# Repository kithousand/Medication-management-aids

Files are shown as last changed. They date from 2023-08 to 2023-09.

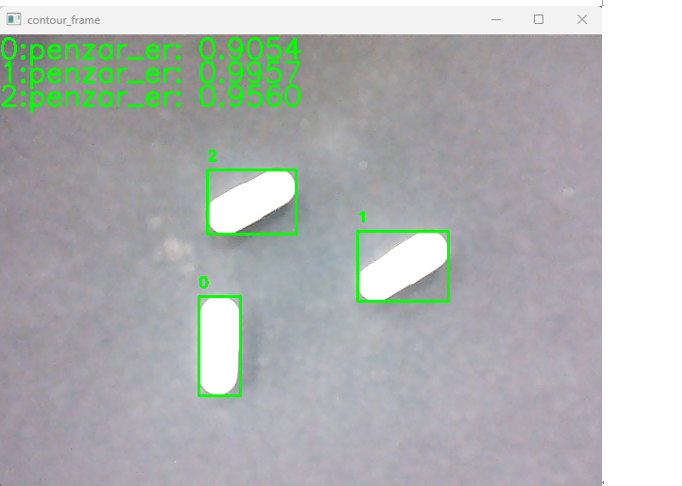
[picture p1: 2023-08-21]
AI/result.png

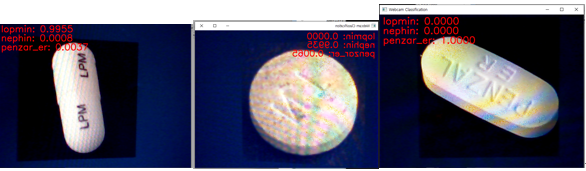
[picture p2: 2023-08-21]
AI/result1.png

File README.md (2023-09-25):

# 팀_알약보조관리


# 문제점정의

## 최근 통계로 알아보는 노인층의 복약관리 동향


## 사용자 분석 – 우리 주변의 노인들


## 사용자 분석 – 전문가 인터뷰


# 유즈케이스 시나리오

고령화 저출산은 한국에서 심각한 사회현상중 하나이다

독거노인들은 복약관리등 케어를 받을 금전적 여유나

인간관계가 부족하기때문에 복약관리를 받기가 쉽지않다

또한 노화에 인한 기억력 감퇴때문에 약을 먹을 시기를 놓치기도 한다

이번프로젝트는 독거노인들이 혼자서 약을 먹는것을 잊지않고 먹게 해주고

실수로 중복약제를 먹는 것을 예방해준다

## High level design


## Work breakdown sheet

									
## 동작구조도


## Flow Chart


## 역할 분담
팀장 하종찬(기획/프로젝트 매니저)

팀원 문상원(개발자, AI 개발)

팀원 한재욱(개발자, 임베디드 개발)

팀원 엄기천(개발자, 알고리즘 개발)

## 그 외 기타 사항 - SW dependency, 동작 환경, 제한 사항 등을 기술

## 핵심 기술


## 시연 영상, 제작영상 URL
• 제작영상 : https://www.youtube.com/watch?v=2JGMzi57F4s&t=31s

• 시연영상 : https://www.youtube.com/shorts/7cosngZtbhQ

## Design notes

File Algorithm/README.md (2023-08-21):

# pill_eat_source - ki_thousand

## 동작환경
OS : Debian GNU/Linux 11 이상
Python : 3.9.2 이상

## 필요한 패키지 설치 : requirements.txt
```
$ pip install -r requirements.txt
```

## 실행파일이름 : main.py

```
$ python3 main.py
```

## class별 pill_eat 기능설명

### Message.py
#### LCD와 SPEAKER로 사용자에게 알림기능파일

```
class Message:
  - welcome_Pilleat(): 웰컴필잇!!!
  - fill_Pill(): 트레이에 알약을 채워달라고 알려주는 기능
  - eatTime_Pill(): 약을 복용해야하는 시간을 알려주는 기능
  - info_Pill(): 약의 이름과 성분 설명해주는 기능
  - overlap_Pill(): 중복된 약을 알려주는 기능
  - loading_Wait(): 로딩중임을 표시하는 기능
  - display_Time_now(): 현재시간을 표시해주는 기능
```

### led.py
#### LED와 SENSOR를 제어하는 파일

```
class led:
  - led_on(): LED를 켜는기능 (주로 알약분석시 활용)
  - led_off(): LED를 끄는기능 

class sensor:
  - sensor_state(): IR SENSOR 감지값을 읽는기능 (TRAY가 있는지 확인할때 사용)
```

### detect_Pill.py
#### AI모델을 사용하는 파일

```
class analysis_pill:
  - analysis_Pill(): TRAY에 있는 알약을 분석하는기능 (LCD와 SPEAKER출력도 포함되어있음)
```

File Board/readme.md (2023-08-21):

# 보드세팅

## 하드웨어 세팅

### 배터리팩 제작
그림1
BMS 보호회로에 각 맞는 리튬이온배터리 단자를 연결해줍니다.
알맞은 입출력단자에 QC3.0 출력단자와 C타입 입력단자를 연결합니다.

### LCD, 카메라, IR 근접센서, LED 모듈 고정
그림4
기존 가공된 외관에 LCD와 카메라, IR 근접센서, LED를 글루건이나 본드로 고정해줍니다.

### 핀 연결
그림5
핀 맵을 참고하여 라즈베리파이에 핀을 연결해줍니다.

### 스피커와 배터리 모듈 연결
그림6
스피커는 라즈베리파이 USB단자에 연결합니다.
배터리팩은 라즈베리파이 C타입전원 단자에 연결합니다.

### 완성본
그림7

## 라즈베리파이 내부 세팅

### Raspberry Pi OS 라즈비안 설치
https://www.raspberrypi.com/software/
접속하여서 OS 소프트웨어를 다운받습니다.
OS로 라즈비안 64-Bit를 선택합니다.

noname01
고급옵션(밑의 톱니바퀴)을 선택하여 SSH 사용과 무선 LAN을 설정해줍니다.
SSH 사용 => 비밀번호 인증 사용 => 사용자 이름 및 비밀번호 설정 => 무선 LAN 설정 => locale 설정 지정

### 라즈베리파이 초기 설정
윈도우 cmd창에서 nmap으로 라즈베리파이의 IP주소를 찾습니다.
```
$ nmap -sn 192.168.0.0/24
```
putty를 실행하여 라즈베리파이에 접속하여 업데이트를 진행해줍니다.
```
$ sudo apt update
```
```
$ sudo apt upgrade
```
/etc/dhcpcd.conf 파일 열어서 라즈베리파이에 고정 IP를 설정합니다
```
$ sudo apt install vim
```
```
$ sudo vim /etc/dhcpcd.conf
```
파일 맨 아래에 아래의 내용을 추가해줍니다.
```
interface wlan0
static ip_address = 
static routers =
```
networking service 재시작해준 이후 reboot해줍니다.
```
$ sudo /etc/init.d/networking restart
```
```
$ sudo reboot
```

### 라즈베리파이 원격 GUI 접속
xrdp를 설치해줍니다.
```
$ sudo apt install xrdp
```
이후 원격접속을 설정해줍니다.
```
$ sudo raspi-config
```
Interface Options => VNC => enable 하기
접속이 안될경우
아래 코드로 원격접속화면을 생성해줍니다.
```
$ vncserver-virtual
$ vncserver-virtual –geometry 1280x1024
```
https://www.realvnc.com/en/connect/download/viewer/
접속하여서 VNC Viewer를 설치합니다.

### 카메라 설정하기
```
$ sudo raspi-config
```
Interface Options => Legacy Camera => enable 하기 => reboot

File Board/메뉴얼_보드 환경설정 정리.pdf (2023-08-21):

1. Raspberry Pi OS 라즈비안 설치
1) OS 소프트웨어 다운
https://www.raspberrypi.com/software/

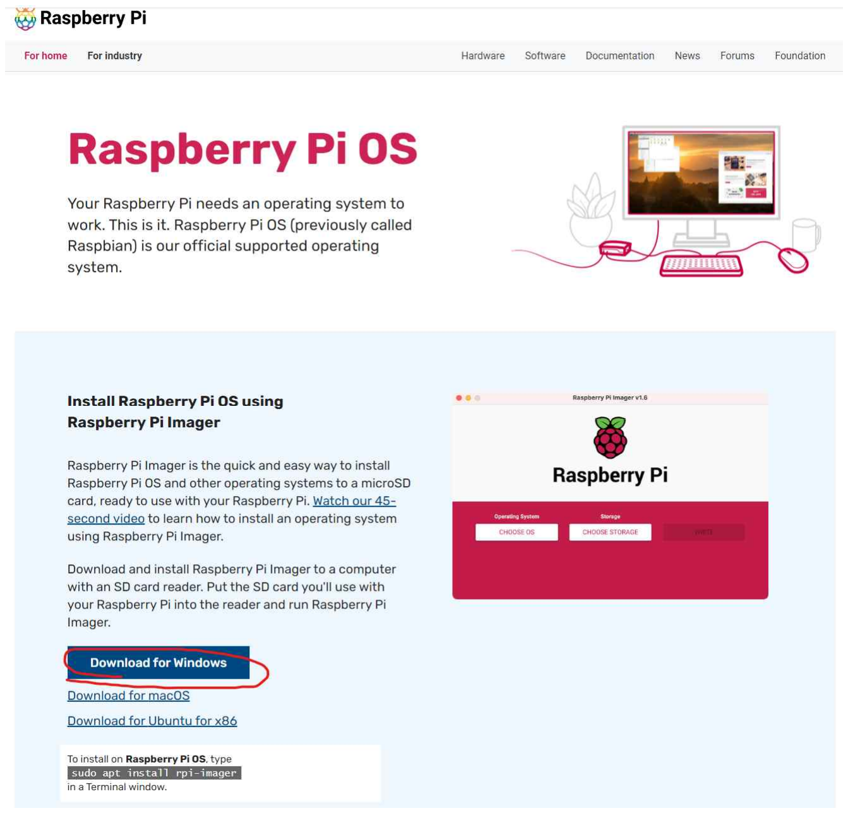
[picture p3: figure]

2) OS 선택

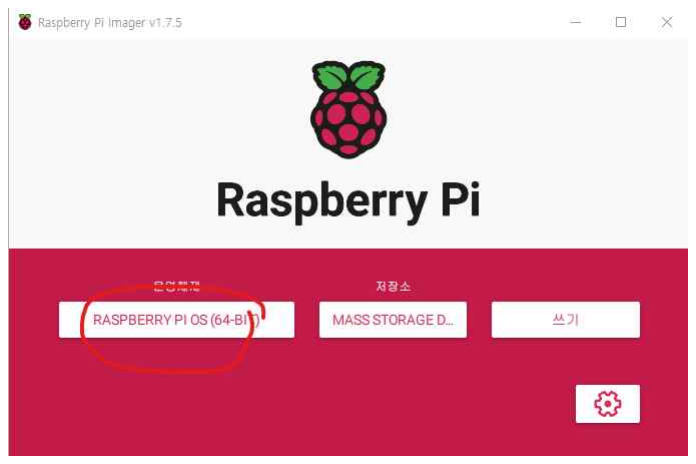
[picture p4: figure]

3) 고급 옵션 설정
SSH 사용 => 비밀번호 인증 사용 => 사용 자 이름 및 비밀번호 설정 => 무선 LAN 설 정 => locale 설정 지정
2. 라즈베리파이 초기 설정
1) 윈도우 cmd창에서 nmap으로 라즈베리
파이 찾기 (같은 네트워크 환경이여야 함)
$ nmap -sn 192.168.0.0/24
2) putty 실행하여 라즈베리파이 접속
Host Name(or IP address)에다 위에서 찾 은 라즈베리파이 IP주소 넣기 ssh 접속
(Open)후 라즈베리파이 OS 설치시 설정한
username과 password 입력

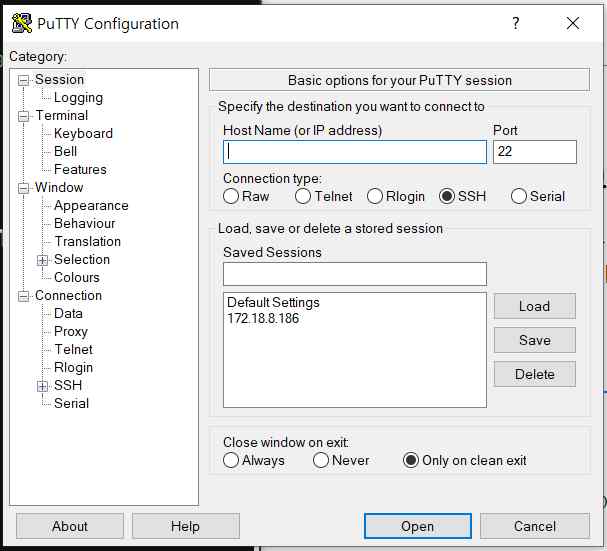
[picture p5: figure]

3) 업데이트
$ sudo apt update

$ sudo apt upgrade

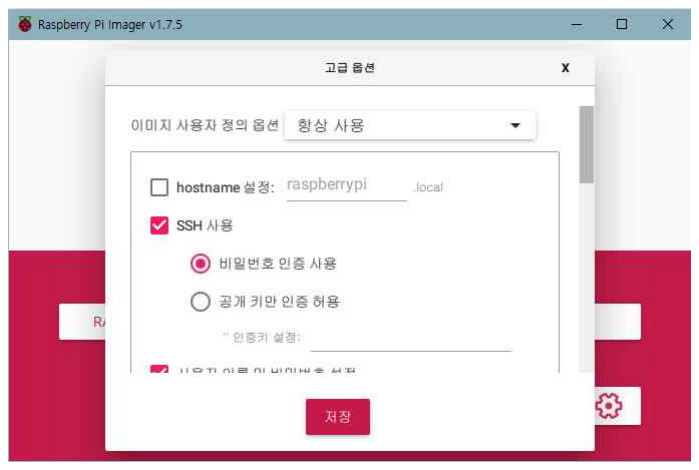
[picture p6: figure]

4) 라즈베리파이 고정 IP 설정하기
/etc/dhcpcd.conf 파일 열어서 수정 $ sudo apt install vim

$ sudo vim /etc/dhcpcd.conf

파일 맨 아래에 아래와 같이 내용 추가

interface wlan0
static ip_address = static routers =

ip_address에는 ifconfig에서 확인한 inet 을, routers에는 ip_address에서 마지막만 1로 바꿔서 입력

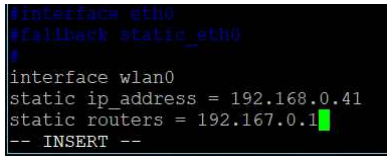
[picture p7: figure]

networking service 재시작
$ sudo /etc/init.d/networking restart

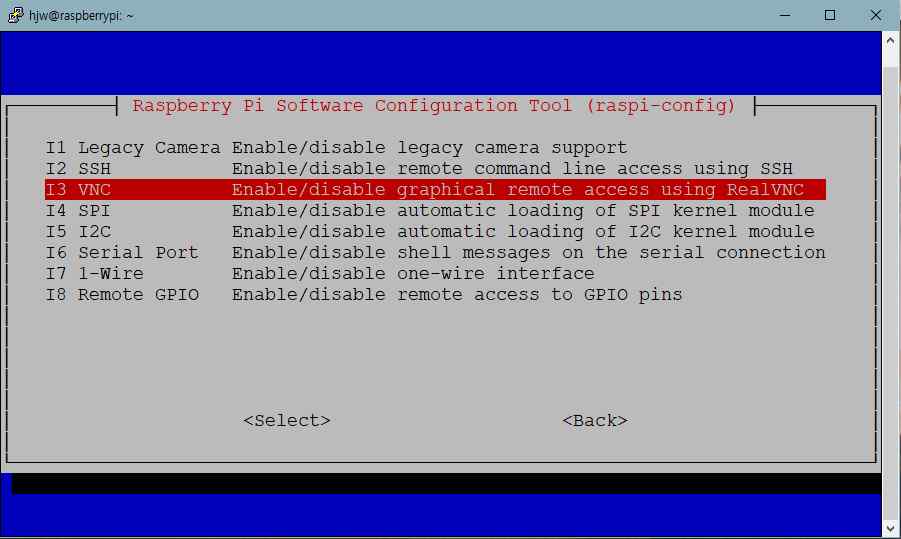
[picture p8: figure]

reboot 해준다
$ sudo reboot
3. 라즈베리파이 원격 GUI 접속
1) xrdp 설치
$ sudo apt install xrdp
2) 원격접속 설정
$ sudo raspi-config

Interface Options => VNC => enable 하 기

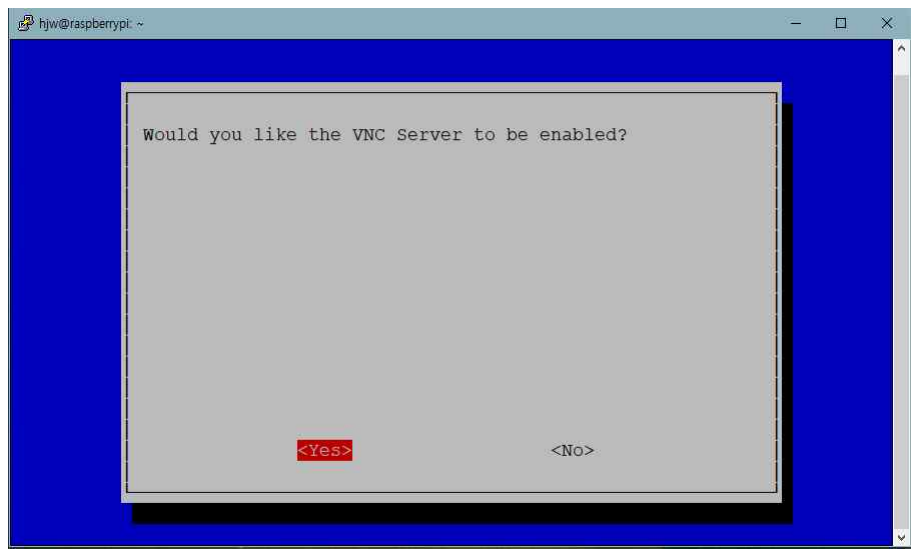
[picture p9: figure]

원격접속화면 생성하기
$ vncserver-virtual

$ vncserver –geometry 1280x1024

VNC Viewer 설치
https://www.realvnc.com/en/connect/download/viewer/

라즈베리파이의 ip 주소를 입력후 접속한다

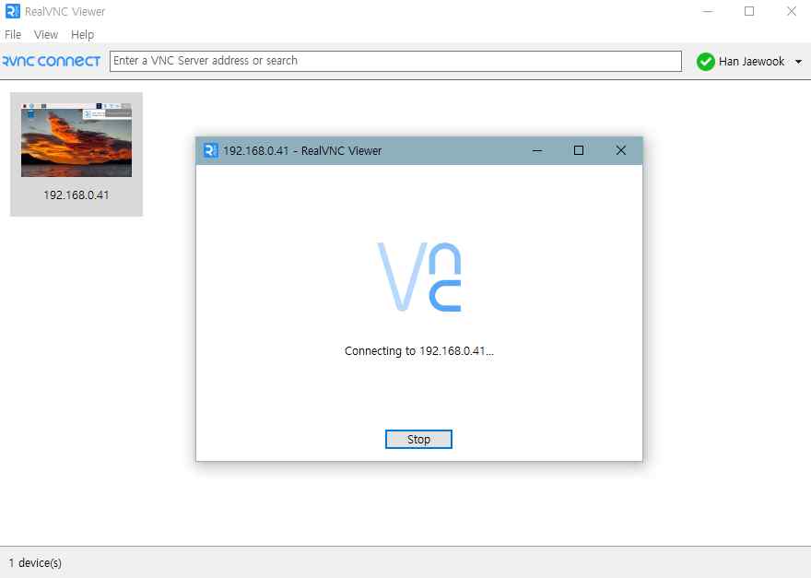
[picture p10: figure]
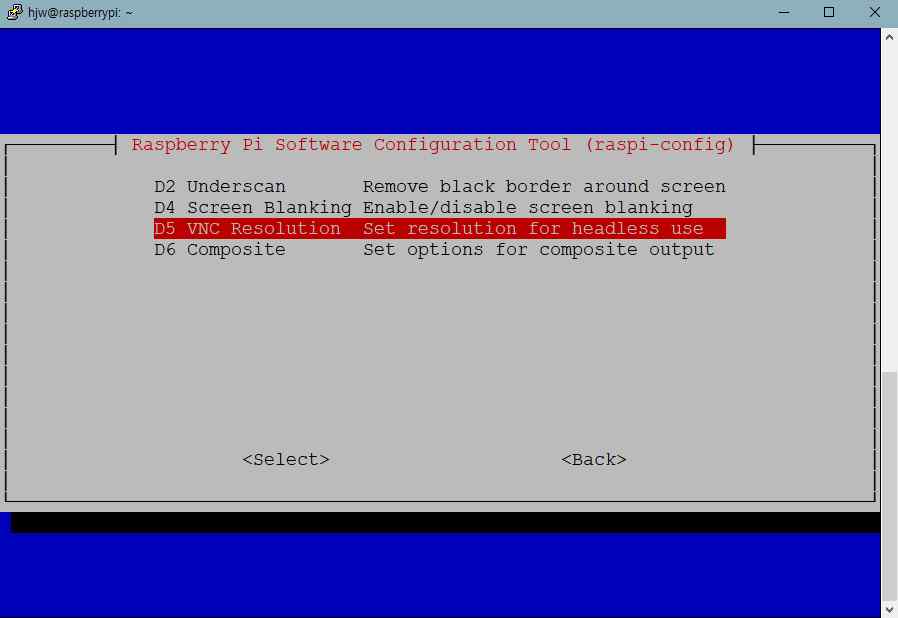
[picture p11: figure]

# Cannot currently show the Desktop 오류가 나올시

/boot/config.txt 파일 수정하기
$ sudo vim /boot/config.txt

아래와 같이 HDMI Mode 설정을 수정한다. #framebuffer_width=

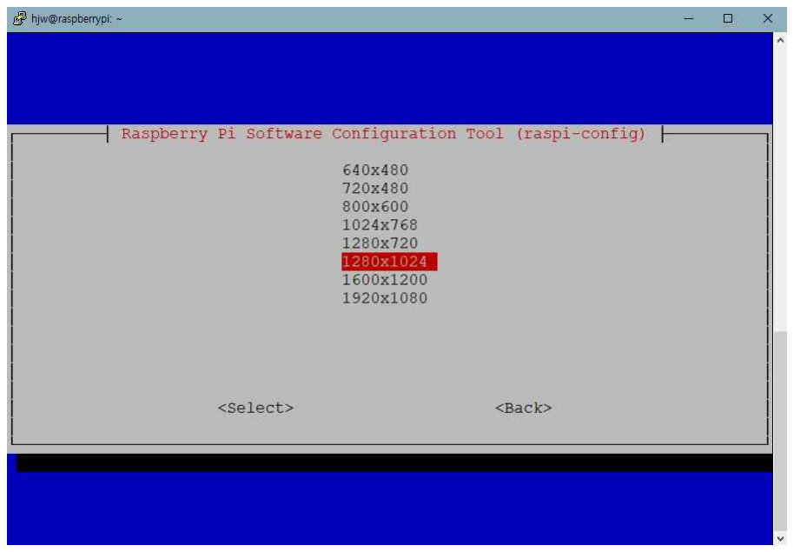
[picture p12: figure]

#framebuffer_height=

#hdmi_force_hotplug=1

#hdmi_group=1

#hdmi_mode=1

# 아래와 같이 수정

framebuffer_width=1280
framebuffer_height=1024

hdmi_force_hotplug=1

hdmi_group=2
hdmi_mode=4

해상도 변경하기
$ sudo raspi-config

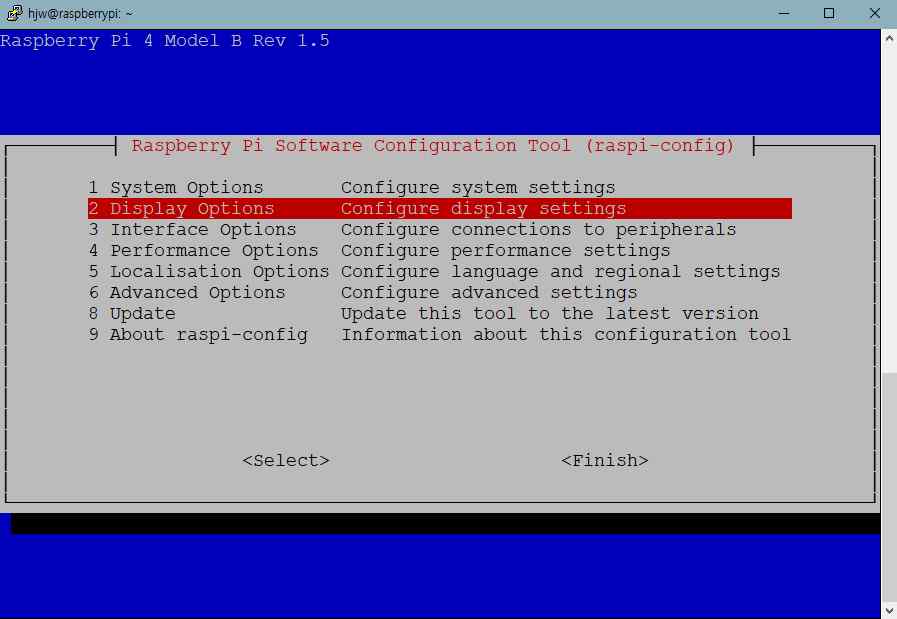
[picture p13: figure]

Display Options => VNC Resolution => 원하는 해상도 선택

4. 카메라 설정하기
$ sudo raspi-config

Interface Options => Legacy Camera => enable 하기 => reboot

5. 필요한 패키지 설치하기
“requirement.txt” 파일에 필요한 패키지 목록이 있습니다. $ pip install –r requirements.txt

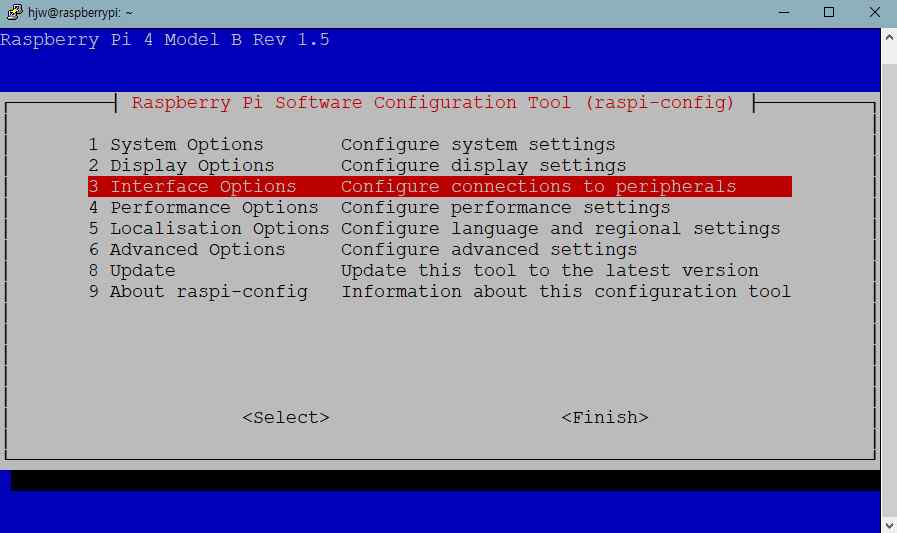
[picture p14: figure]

위의 명령어를 실행하면 모든 환경설정이 완
료됩니다.

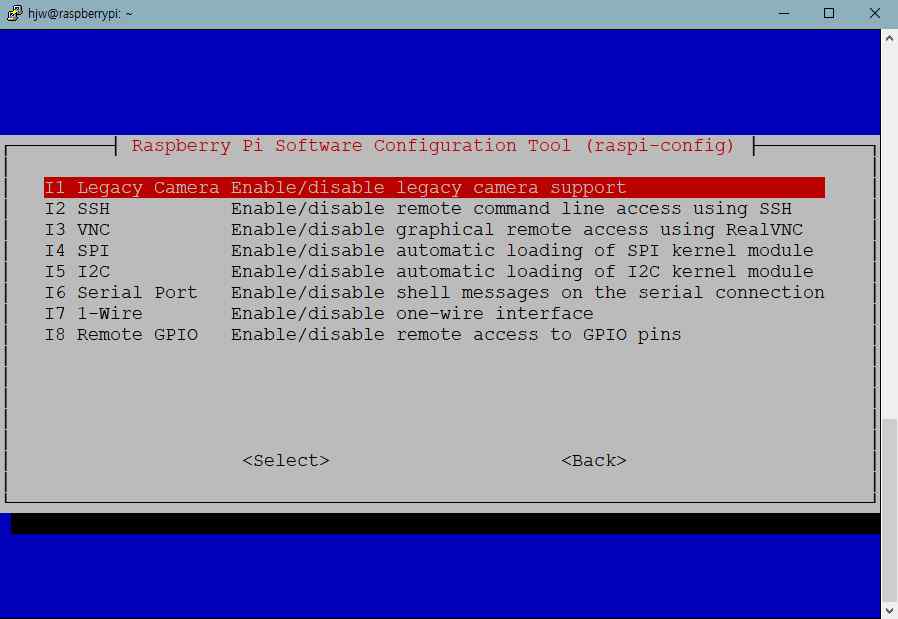
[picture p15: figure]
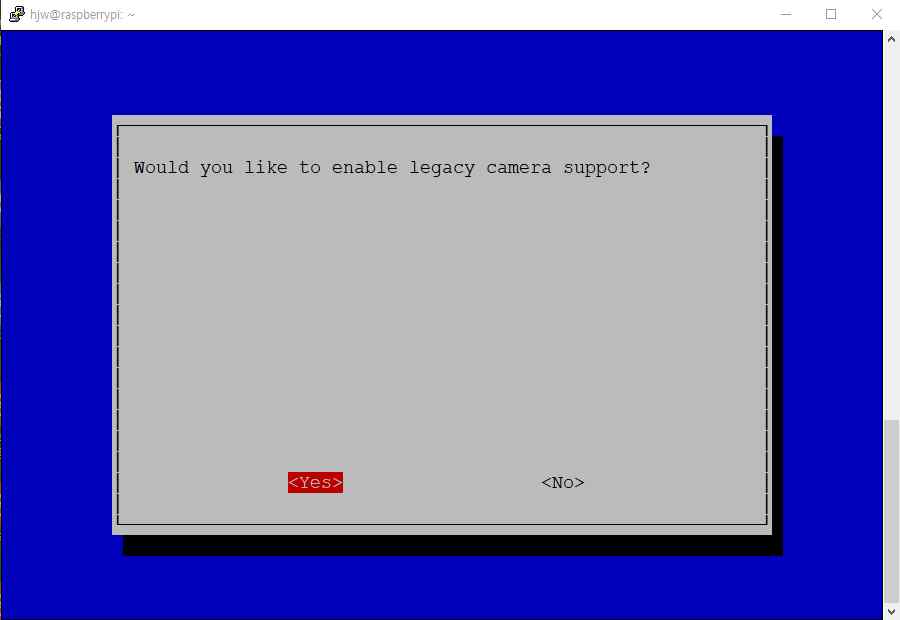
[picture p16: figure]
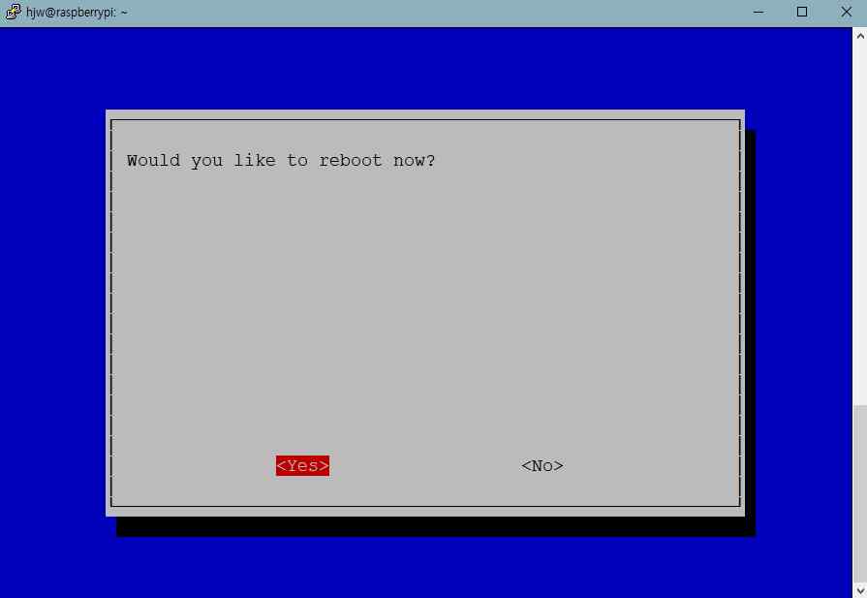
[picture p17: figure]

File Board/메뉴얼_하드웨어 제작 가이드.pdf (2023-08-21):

# 알약관리 보조기기 하드웨어 제작 가이드

팀 : 나 지금 필받았어
하드웨어담당 : 한재욱

# 배터리팩 제작

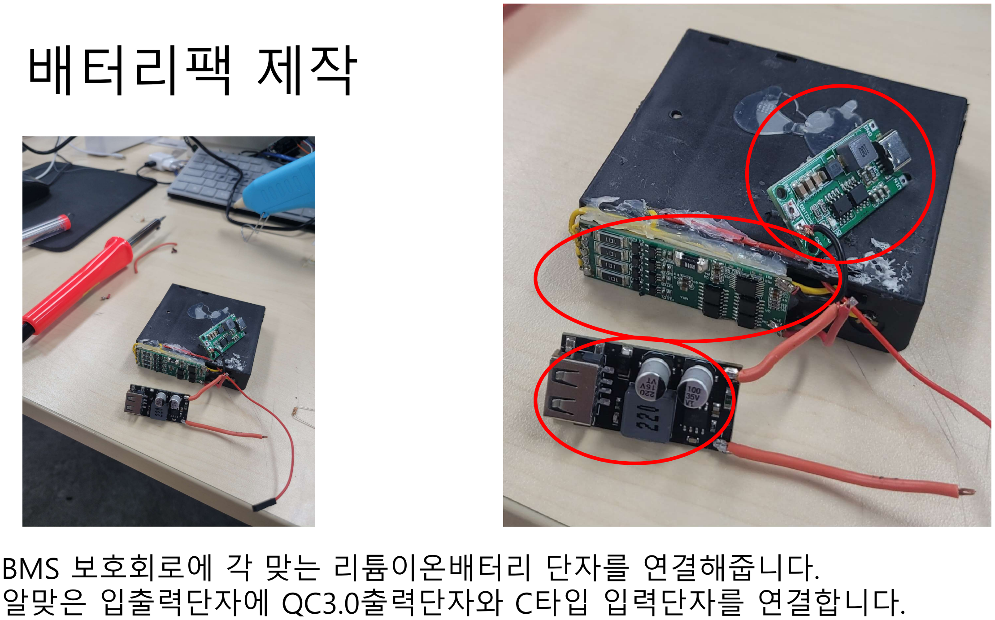
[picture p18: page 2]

BMS 보호회로에 각 맞는 리튬이온배터리 단자를 연결해줍니다. 알맞은 입출력단자에 QC3.0출력단자와 C타입 입력단자를 연결합니다.

# LCD, 카메라, IR 근접센서, LED 모듈 고정

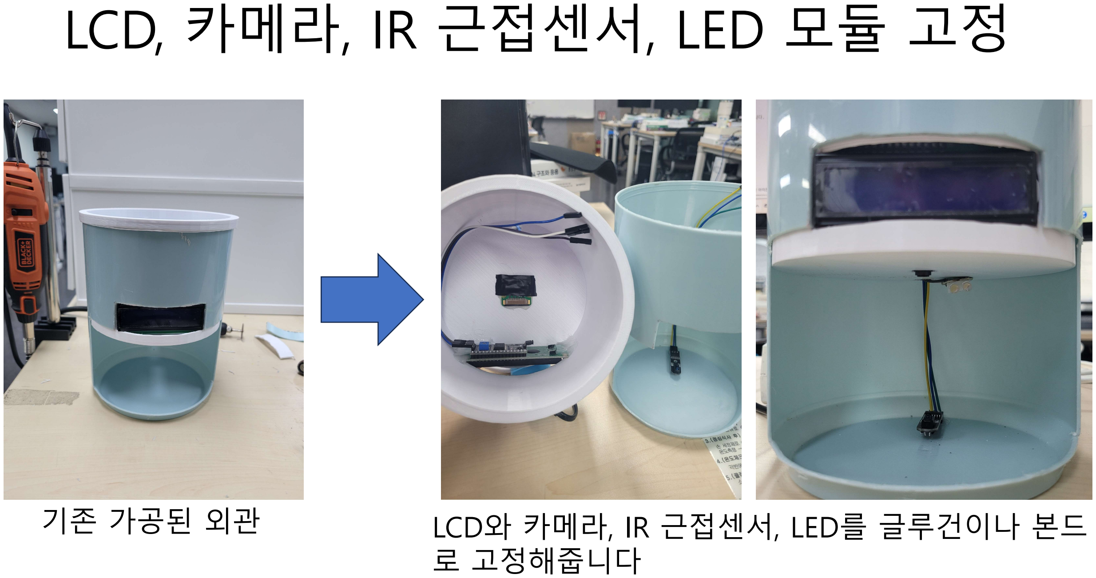
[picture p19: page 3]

기존 가공된 외관 | LCD와 카메라, IR 근접센서, LED를 글루건이나 본드 로 고정해줍니다

# 핀 연결

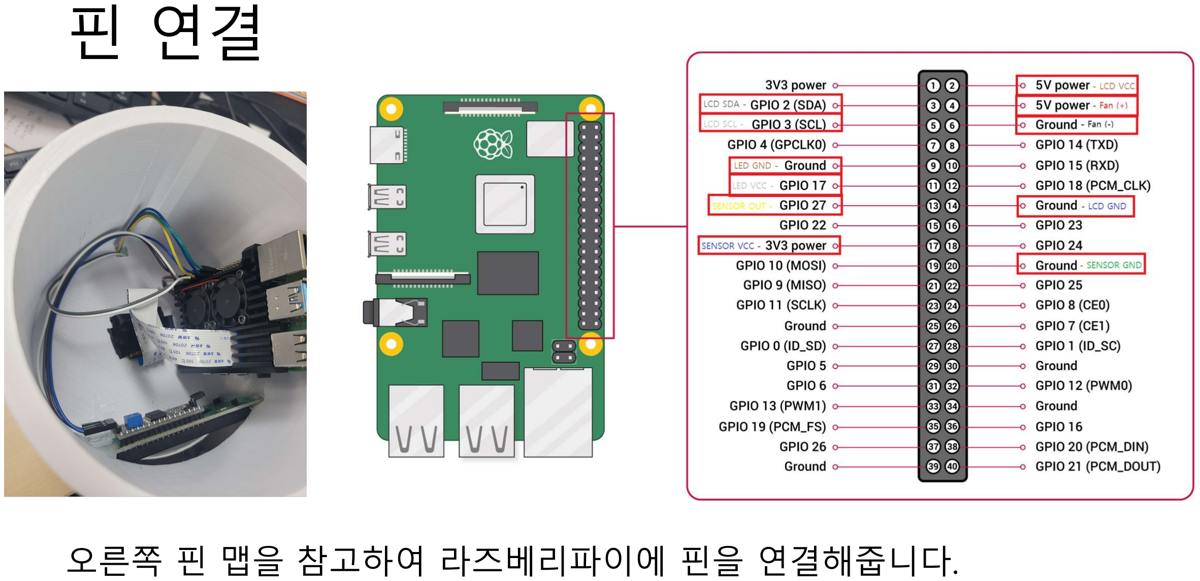
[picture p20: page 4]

오른쪽 핀 맵을 참고하여 라즈베리파이에 핀을 연결해줍니다.

# 스피커와 배터리 모듈 연결

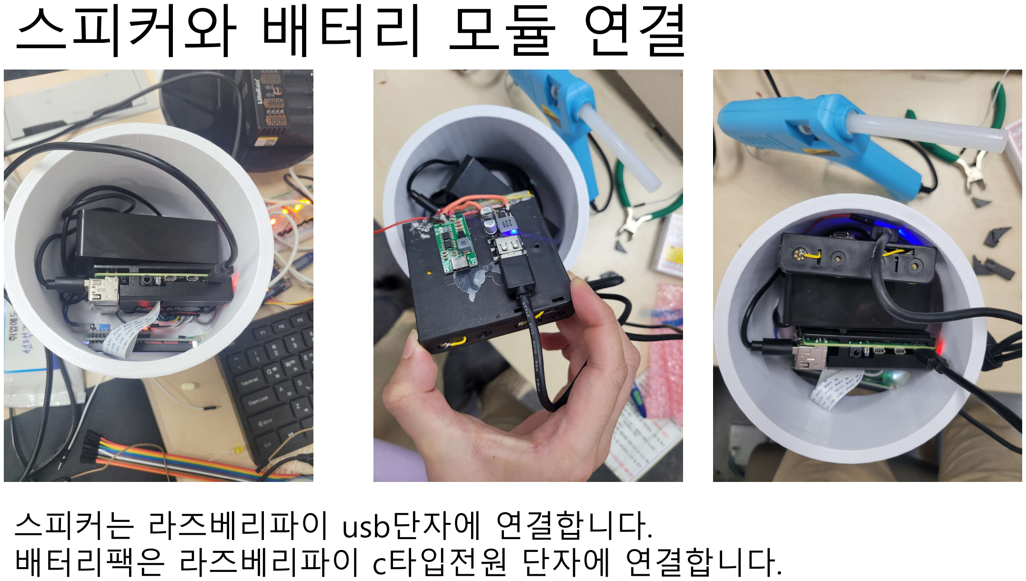
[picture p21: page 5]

스피커는 라즈베리파이 usb단자에 연결합니다.
배터리팩은 라즈베리파이 c타입전원 단자에 연결합니다.

# 완성본

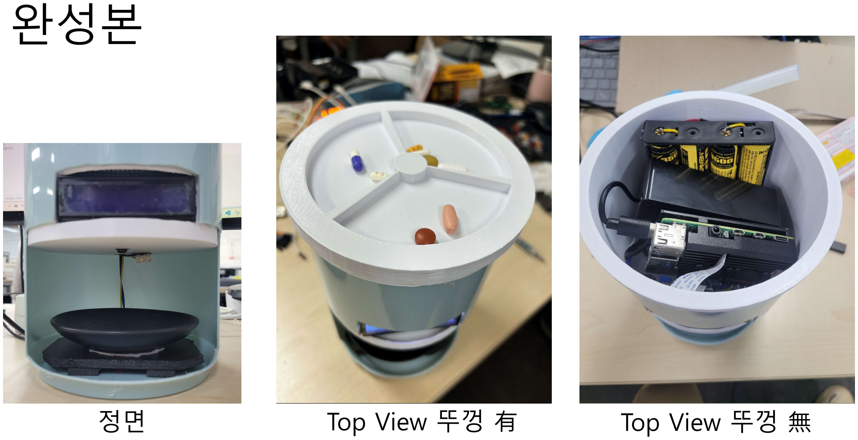
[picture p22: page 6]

정면 | Top View 뚜껑 有 | Top View 뚜껑 無

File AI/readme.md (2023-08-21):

# 알약 객체 분류 AI

## 프로젝트 소개
- 국립 재활원 제 4회 해커톤 본선 진출프로젝트
## 사용방법 
- pip install -r requirement.txt
## AI모델 설계
- 모든 알약은 제조사나 성분에 따라 모두 다른형태를 가진다 이런 알약의 특성을 이용해
- 이미지 분류 AI를 만들어 시력감소나 기억력 감퇴로 약제 구별에 어려움을 격는 취약계층에 도움을 제공한다

## AI모델 제작과정
- 전이학습을 이용한 모델입니다
- resNet-18 아키텍쳐를 사용하였습니다
- 로프민 네프신 펜잘을 3종류를 분류할수있는 AI입니다

## 약제 관련정보 

- 로프민 
http://www.health.kr/searchDrug/result_drug.asp?drug_cd=A11A1660A0057

- 네프신 
https://www.health.kr/searchDrug/result_drug.asp?drug_cd=2014121100005

- 펜잘8시간이알서방정 
https://www.health.kr/searchDrug/result_drug.asp?drug_cd=2013103000013

## 데이터셋 출처
- https://aihub.or.kr/aihubdata/data/view.do?dataSetSn=576
경구약제 이미지데이터

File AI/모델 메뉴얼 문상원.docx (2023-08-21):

# 모델 설계

## AI모델 설계 이유와 필요성

알약은 모든 알약 특성상 성분과 제조기업 등에 따라 다른 형태를 가지고 있습니다

저희는 이런 알약의 특성을 파악하는 이미지 분류 AI를 만들어

시력감소나 기억력감퇴로 약제의 구별에 어려움을 격고있는

취약계층에게 도움을 제공하려 합니다

중복약제를 약을 복용하기 전에 걸러줘

복약지도를 받기 어려운 환경을 개선해주고

취약계층의 질병예방과 건강 개선이 목적입니다.

## 모델 제작과정

이 알약분류모델은 정확도와 해커톤 특성상 부족한 시간을 고려하여

전이 학습을 통해 만들었습니다

ResNet-18아키텍처를 사용하였습니다

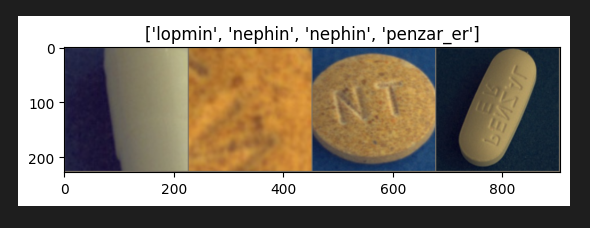
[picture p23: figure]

학습데이터는 로프민 캡슐

로프민캡슐 Lopmin Cap. 의약품 정보 (health.kr) (http://www.health.kr/searchDrug/result_drug.asp?drug_cd=A11A1660A0057)

네프신정

네프신정 Nephcin Tab. 의약품 정보 (health.kr) (https://www.health.kr/searchDrug/result_drug.asp?drug_cd=2014121100005)

펜잘8시간이알서방정

펜잘8시간이알서방정 Penzal 8 hours ER Tab. 의약품 정보 (health.kr) (https://www.health.kr/searchDrug/result_drug.asp?drug_cd=2013103000013)

3개를 분류할 수 있는 AI를 제작하였습니다

데이터셋은

AI-Hub (aihub.or.kr) (https://aihub.or.kr/aihubdata/data/view.do?dataSetSn=576)

경구약제 이미지데이터에서 제공받았습니다

## 모델 결과

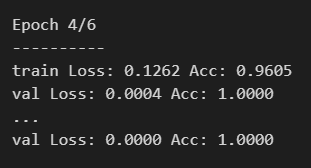
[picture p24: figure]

정확도는 95퍼정도로 좋은 수치입니다

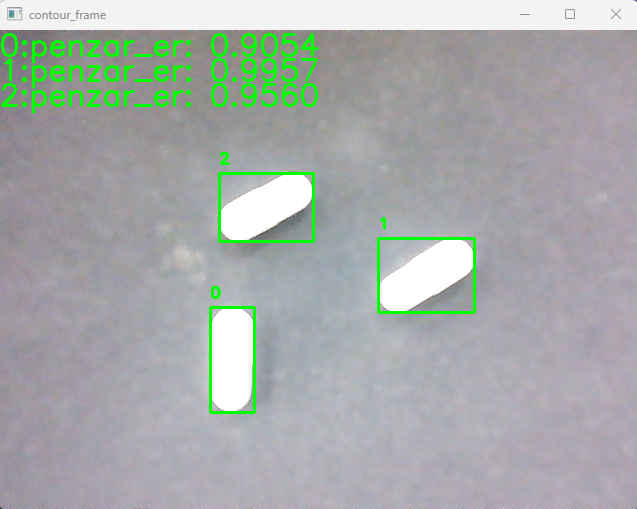
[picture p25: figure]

실제 구동영상으로 높은 확률로 맞는 알약을 구분해 내는 것을 확인 할 수 있습니다

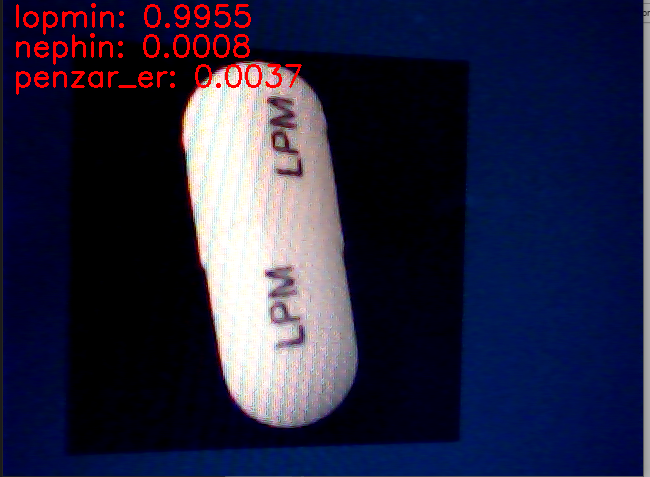
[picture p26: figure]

기존에 7000개 종류에서 이미지 데이터셋을 가져와 선택하여 사용하였습니다.

최적화를 위해서 시범적으로 3개만 포함했지만

리소스와 시간만 충분하다면 추후 7000가지로도 분류가 가능할 것입니다

## 시연 화면


실시간으로 이미지의 모든 알약을 파악하여

분류모델로 어떤 알약이 있는지 분류하는 것을 보실 수 있습니다

위와 같은 구동방식으로 저희는 중복약제 복용을 노인 분들이 먹기 전에 체크해주고

중복약제가 있을 경우 다시 한번 확인 할 것을 요청 드릴 수 있습니다

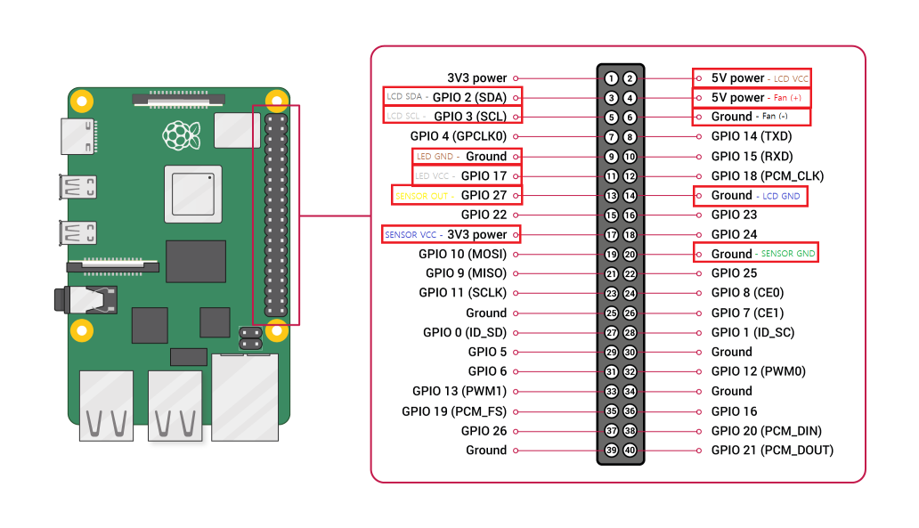
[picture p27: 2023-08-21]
Board/picture/그림5.png

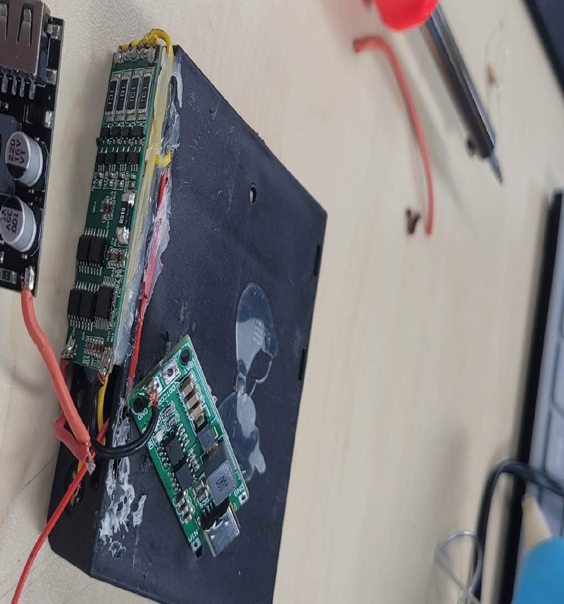
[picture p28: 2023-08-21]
Board/picture/그림1.jpg

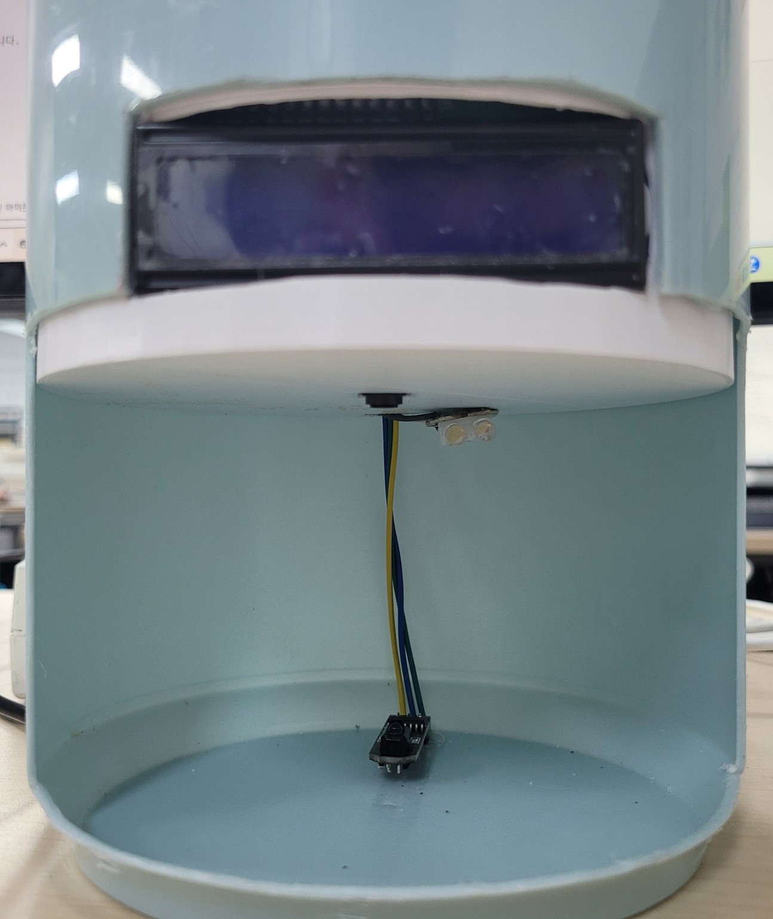
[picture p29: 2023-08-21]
Board/picture/그림3.jpg

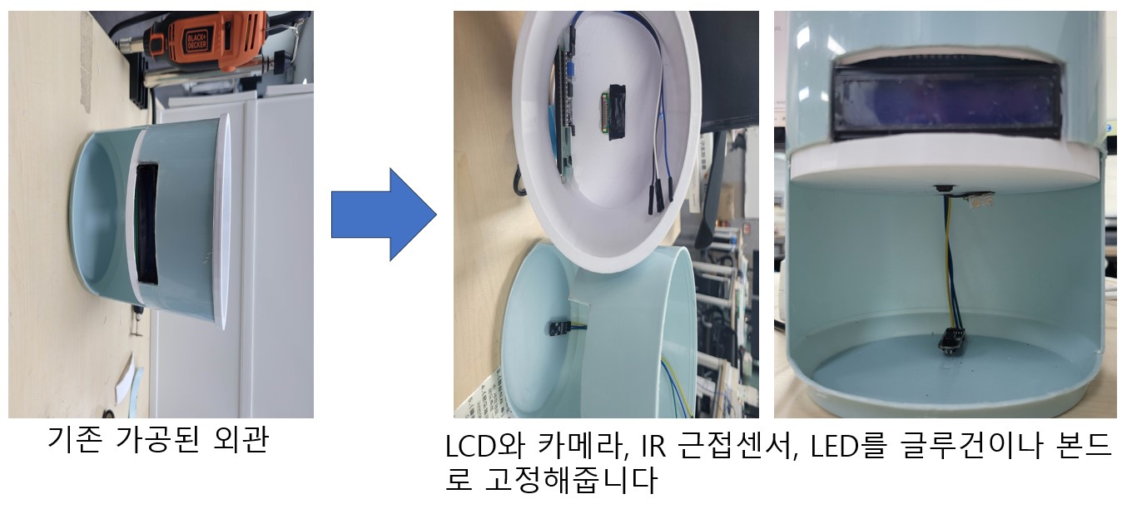
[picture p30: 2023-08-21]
Board/picture/그림4.jpg

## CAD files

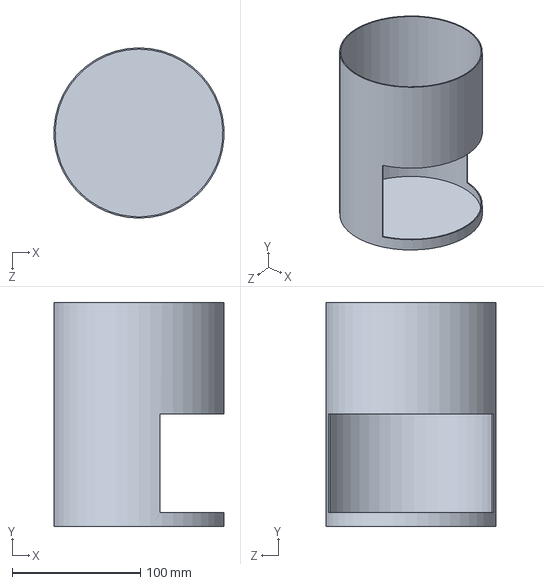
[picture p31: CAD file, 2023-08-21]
3D models/trashbin_v2.SLDPRT
132.7 x 175.0 x 133.0 mm

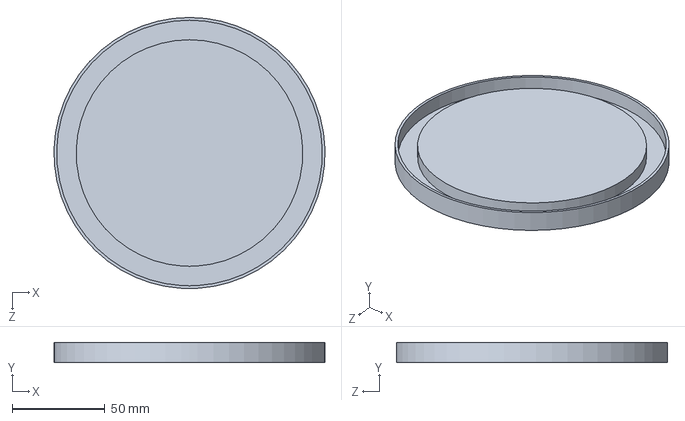
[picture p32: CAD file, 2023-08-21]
3D models/drug_kit_v2.SLDPRT
145.9 x 11.0 x 146.0 mm

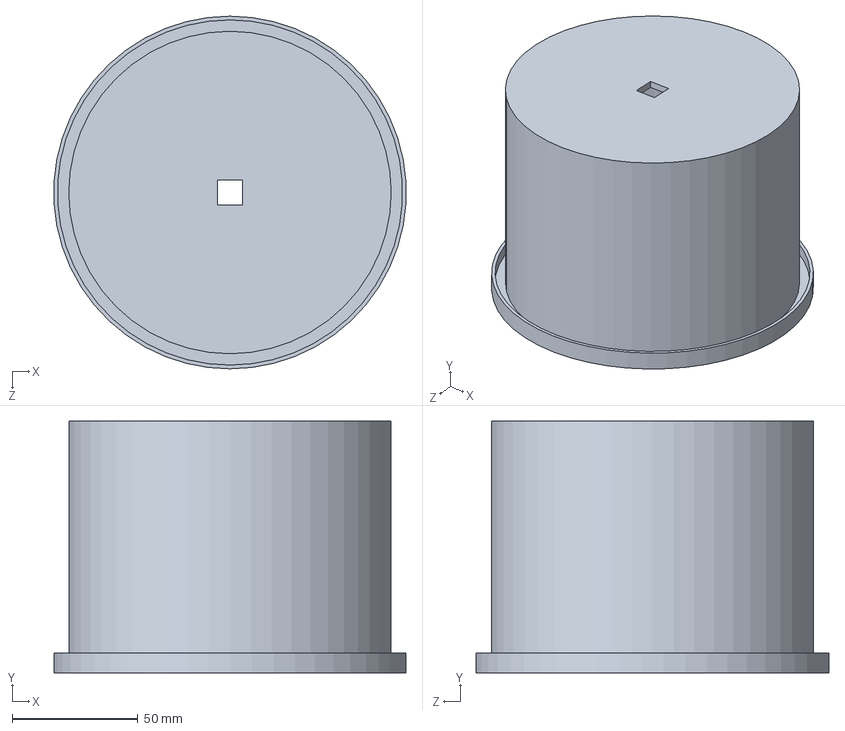
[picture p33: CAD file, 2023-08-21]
3D models/pcb_plate_v2.SLDPRT
139.7 x 100.0 x 140.0 mm

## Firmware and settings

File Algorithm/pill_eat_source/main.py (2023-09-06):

import os
import RPi_I2C_driver 
import Message
import led
import detect_Pill

from flask import Flask, render_template, Response
import threading
from queue import Queue

from time import *
from datetime import datetime
import RPi.GPIO as GPIO

GPIO.setmode(GPIO.BCM)
GPIO.setup(17,GPIO.OUT)
GPIO.setup(27,GPIO.IN)

 
LCD = RPi_I2C_driver.lcd()
MESSAGE = Message.Message()
ANAL = detect_Pill.analysis_pill()
LED = led.led()
SENSOR = led.sensor()



if __name__ == '__main__':
    #전원들어가면
    #웰컴보이스
    MESSAGE.welcome_Pilleat() 
    MESSAGE.fill_Pill()
    while(True):
       #현재시간출력
       MESSAGE.display_Time_now()
       sleep(3)
      
       #일정시간되면 
       if MESSAGE.display_Time_morning == True:
       
       MESSAGE.eatTime_Pill()
       MESSAGE.fill_Pill()
    
       while(True):
            #트레이 들어오면   
            if SENSOR.sensor_state() == True:
                LED.led_on()
                MESSAGE.loading_Wait() 
                ANAL.analysis_Pill()
                LED.led_off()
                break   
            else:
                MESSAGE.fill_Pill()
           
        
    LCD.backlight(0)
    LED.led_off()
GPIO.cleanup()

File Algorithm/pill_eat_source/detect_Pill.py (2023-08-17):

import torch
import torchvision.transforms as transforms
import onnxruntime
import cv2
import os
from PIL import Image
import Message
from time import *

from flask import Flask, render_template, Response
import threading
from queue import Queue


MESSAGE = Message.Message()

class analysis_pill:
    def analysis_Pill(self):
        # 큐 생성
        frame_queue = Queue()
        # 스레드 종료를 위한 플래그
        thread_exit_flag = False

        app = Flask(__name__)

        def generate_frames():
            while True:
                # 큐에서 프레임 가져오기
                frame = frame_queue.get()

                # 프레임을 바이트 스트림으로 인코딩하여 전송
                _, buffer = cv2.imencode('.jpg', frame)
                frame = buffer.tobytes()
                yield (b'--frame\r\n'
                       b'Content-Type: image/jpeg\r\n\r\n' + frame + b'\r\n')
                break
                #과부하시 딜레이넣을것
                time.sleep(1)



       
        @app.route('/')
        def index():
            return render_template('index.html')
        @app.route('/video_feed')
        def video_feed():
            return Response(generate_frames(), mimetype='multipart/x-mixed-replace; boundary=frame')
        @app.route('/events')
        def events():
            def generate():
                while True:
                    readytosend=send_text
                    sse_message= f"data: {readytosend}\n\n"
                    yield sse_message
                    #time.sleep(1)
        
            return Response(generate(), content_type='text/event-stream')
    
        def start_stream():
            app.run(host='0.0.0.0', port=8000, debug=False)
        
        
        server_thread = threading.Thread(target=start_stream)
        
        
        server_thread.start()
        
        def start_stream():
            app.run(debug=False)
        
    
    

        #이미지 전처리를 위한 변환 정의
        transform = transforms.Compose([
            transforms.Resize(256),
            transforms.CenterCrop(224),
            transforms.ToTensor(),
            transforms.Normalize(mean=[0.485, 0.456, 0.406], std=[0.229, 0.224, 0.225]),
        ])  
        # ONNX 모델을 ONNX Runtime으로 로드
        ort_session = onnxruntime.InferenceSession('/home/pill/pill_eat/model_ft.onnx') 
        # 클래스 이름 목록
        class_names = ['lopmin', 'nephin', 'penzar_er']

        # 모델을 GPU로 이동 없으면 cpu
        device = torch.device("cuda" if torch.cuda.is_available() else "cpu")
        print(device)
        print(f"Using device: {device}")
        ort_session.set_providers([f'CUDAExecutionProvider'])
        ort_session.set_providers([f'CPUExecutionProvider'])






        # 결과 저장 배열
        detected_classes = []   
        cap = cv2.VideoCapture(0)  # 웹캠 캡처 객체 생성

        while (True):
            ret, frame = cap.read()

            if not ret:
                break
            
            
            # 프레임을 화면에 보여주기
            #cv2.imshow('Webcam', frame)
            gray_frame = cv2.cvtColor(frame, cv2.COLOR_BGR2GRAY)
            _, binary_frame = cv2.threshold(gray_frame,150, 255, cv2.THRESH_BINARY)
            # 노이즈 제거를 위한 침식과 팽창 연산
            kernel = cv2.getStructuringElement(cv2.MORPH_RECT, (5, 5))
            eroded_frame = cv2.erode(binary_frame, kernel, iterations=1)
            dilated_frame = cv2.dilate(eroded_frame, kernel, iterations=1)
            #cv2.imshow('Denoised Webcam', dilated_frame)
            # 원본프레임 복사
            contour_frame = frame.copy()
            # 컨투어 찾기
            contours, _ = cv2.findContours(dilated_frame, cv2.RETR_EXTERNAL, cv2.CHAIN_APPROX_SIMPLE)
            # 이미지 리스트 초기화
            roi_images = []
            # 결과 저장 배열 초기화
            detected_classes = []
            count = 0
            for idx, contour in enumerate(contours):
                contour_area = cv2.contourArea(contour)
                if 2000 < contour_area < 55000:
                    x, y, w, h = cv2.boundingRect(contour)
                    cv2.rectangle(contour_frame, (x, y), (x + w , y + h ), (0, 255, 0), 2)
                    # cv2.rectangle(contour_frame, (x, y), (x + w + 20, y + h + 20), (0, 255, 0), 2)
                    #roi = frame[y:y + h+20, x:x + w+20]
                    roi = frame[y:y + h, x:x + w]
                    roi_images.append(roi)  # 이미지를 리스트에 추가
                    # 바운딩 박스 근처에 인덱스 번호 출력
                    cv2.putText(contour_frame, str(count), (x, y - 10), cv2.FONT_HERSHEY_SIMPLEX, 0.5, (0, 255, 0), 2)
                    count=count+1
            count = 0
            text_y_val = 25
            for idx, roi in enumerate(roi_images):
                #cv2.imshow(f'ROI {idx}', roi)
                # 프레임 전처리
                image = Image.fromarray(roi)
                input_tensor = transform(image)
                input_tensor = input_tensor.unsqueeze(0)  # 배치 차원 추가
                # 추론 수행
                ort_inputs = {ort_session.get_inputs()[0].name: input_tensor.numpy()}
                ort_outs = ort_session.run(None, ort_inputs)
                # 클래스별 확률 계산
                output_probs = torch.softmax(torch.tensor(ort_outs[0]), dim=1)
                # 가장 높은 확률을 가진 클래스 정보 출력
                max_prob = torch.max(output_probs[0])
                max_prob_index = torch.argmax(output_probs[0])
                predicted_class = class_names[max_prob_index]
                # 클래스와 확률 문자열
                text = f'{count}:{predicted_class}: {max_prob:.4f}'  # 클래스와 확률 정보 생성
                # 클래스와 확률 화면에 보이기
                cv2.putText(contour_frame, text, (0, text_y_val), cv2.FONT_HERSHEY_SIMPLEX, 1, (0, 255, 0), 2)
                text_y_val = text_y_val + 25
                # 클래스 결과 배열에 추가
                detected_classes.append(predicted_class)
                #cv2.imshow("contour_frame",contour_frame)

                #컨투어 프레임 큐에 넣기
                frame_queue.put(contour_frame)
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

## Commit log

2023-08-17 Update readme.md
    0817_엄기천
2023-08-21 Update Board readme.md v1
    업데이트 1버전입니다
2023-08-21 Add files via upload
    3D models, drug kit, pcb_plate, trashbin
    [drug_kit_v2.SLDPRT, pcb_plate_v2.SLDPRT, trashbin_v2.SLDPRT]
2023-08-21 Update Board readme.md
    보드세팅 설명 내용 업데이트
2023-08-21 board 업데이트
2023-08-21 readme & 다제약물복용현황 추가
